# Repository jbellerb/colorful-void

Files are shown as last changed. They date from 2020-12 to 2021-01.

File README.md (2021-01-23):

# Colorful Void

This is a monorepo for "colorful void", a work-in-progress smart accent light built from a recycled monitor's backlight assembly. See each folder for specific instructions about each component.

## Usage

At it's core, this project is an internet connected light, controllable with a simple JSON-based REST API. The lights in the panel are connected to a Raspberry Pi Zero W running [void-client](void-client/), which exposes an internal control API. While this API is designed to be platform-agnostic, the client is intended to be used with [void-server](void-server/), a relay server that allows the Google Smart Home platform to communicate with the light.

## Security

The void-client API is unsecured and should **never** be exposed to the public internet. While security was a goal of both programs, attack surface mitigation is always helpful—especially since void-client is running as root. If possible, run void-client and void-server on different machines and make sure the Raspberry Pi cannot be accessed from the internet. A VPN solution like Wireguard should be used to enable communication between the two machines.

## Google Smart Home Setup

Usage with the Google Smart Home platform is functional, but some usability aspects are incomplete, such as the lack of a proper login form and requiring a full setup every time void-server is restarted. These steps assume void-client is built and running on a Pi, void-server is built and running on a publically accessable domain with HTTPS, and there is some way for the two to talk (such as a Wireguard tunnel)

### Action Setup

First you must create an Actions on Google project. This is covered in steps 1-6 of [this Google Smart Home documentation page](https://developers.google.com/assistant/smarthome/develop/create#create-project). After that, click on "Account linking" in the side bar and fill out the OAuth Client Information. Client ID should be "google" and Client Secret should be whatever you set when building void-server. The Authorization URL should be `https://whatever-url-you-are-hosting-void-server-at/auth` and the Token URL is `https://whatever-url-you-are-hosting-void-server-at/token`. Finally, click on "Actions" in the side bar and set the Fulfillment URL to `https://whatever-url-you-are-hosting-void-server-at/fulfillment`.

### Logging In

To actually control the light, you need to log in using the Google Home app. In the app, tap Settings, Works with Google, and then whatever you named your Action (which should be prefixed by [test]). This will open a browser window which will 404 because I didn't bother to write a proper login endpoint. To login, you will need to rewrite the URL to another one. Given `https://whaterver-url-you-are-hosting-void-server-at/auth?...&state={state string}&...` visit `https://oauth-redirect.googleusercontent.com/r/{your Actions project id}?code={your authorization token from building void-server}&state={state string from earlier}`. The Google Home app should open again. Follow the remaining instructions in the app and the device should be set up.

<br />

#### License

<sup>
Copyright (C) Jared Beller, 2020-2021.
</sup>
<br />
<sup>
Released under the <a href="https://www.gnu.org/licenses/gpl-3.0.txt">GNU General Public License, Version 3</a> or later. See <a href="LICENSE">LICENSE</a> for more information.
</sup>

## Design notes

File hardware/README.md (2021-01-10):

# hardware

This folder contains hardware schematics and an optional controller PCB for connecting the control Raspberry Pi Zero W to the panel's WS2812 LED strip.

## Usage

The Raspberry Pi outputs at 3.3V while the WS2812 LEDs require 5V control signals, so a level shifter is needed to connect the two. For convenience, a PCB was designed to sit over the upper half of the Raspberry Pi's GPIO pins and interface between it and the LEDs. The PCB also routes power for both the LEDs and Pi, so only a single power supply is needed. Out of an abundance of caution, a 5V 4A power supply ([Adafruit product 1466](https://www.adafruit.com/product/1466)) was used to power the prototype. While the PCB is recommended for reliability, everything can also be hand-wired. When hand-wiring, pins 4-13 (excluding 7) of the SN74AHCT125 level shifter can be left disconnected. The data signal was not reliable on a breadboard, so building with one is not recommended. All components were purchased from Adafruit and are linked below.

## Bill of Materials

| Ref | Description | Part No. | Adafruit PID |
| --- | --- | --- | --- |
| J1  | Raspberry Pi Zero W Pins 1-12 | Zero W | [3400][P1] |
| J2  | 2-Pin 0.1" Pitch Terminal Block | KF120-2P | [2138][P2] |
| J3  | 3-Pin 0.1" Pitch Terminal Block | KF120-3P | [2136][P3] |
| U1  | Quad 3V to 5V Level-Shifter | SN74AHCT125 | [1787][P4] |
| R1  | 470 Ohm Resistor (1/4 Watt) | CF1/4WXJ470 | [2781][P5] |

[P1]: https://www.adafruit.com/product/3400
[P2]: https://www.adafruit.com/product/2138
[P3]: https://www.adafruit.com/product/2136
[P4]: https://www.adafruit.com/product/1787
[P5]: https://www.adafruit.com/product/2781

<br />

#### License

<sup>
Copyright (C) Jared Beller, 2021.
</sup>
<br />
<sup>
Released under the <a href="https://www.gnu.org/licenses/gpl-3.0.txt">GNU General Public License, Version 3</a> or later. See <a href="LICENSE">LICENSE</a> for more information.
</sup>

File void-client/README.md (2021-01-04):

# void-client

This folder contains software to control the panel's LED strip over the network.

## Building

This project requires a recent version of the Rust arm-unknown-linux-gnueabihf toolchain as well as libclang. See the README of [rs_ws281x](https://github.com/rpi-ws281x/rpi-ws281x-rust) for more information about setting this up. This program assumes the LED strip in the panel has 75 lights. If this is not the case for your build, modify the const `LED_COUNT` in [src/light.rs](src/light.rs).

## Usage

This program needs root permissions to run. Logging output is configured with the `RUST_LOG` environment variable. An example systemd unit file is provided in [../infrastructure/void-client.service](../infrastructure/void-client.service).

<br />

#### License

<sup>
Copyright (C) Jared Beller, 2020.
</sup>
<br />
<sup>
Released under the <a href="https://www.gnu.org/licenses/gpl-3.0.txt">GNU General Public License, Version 3</a> or later. See <a href="LICENSE">LICENSE</a> for more information.
</sup>

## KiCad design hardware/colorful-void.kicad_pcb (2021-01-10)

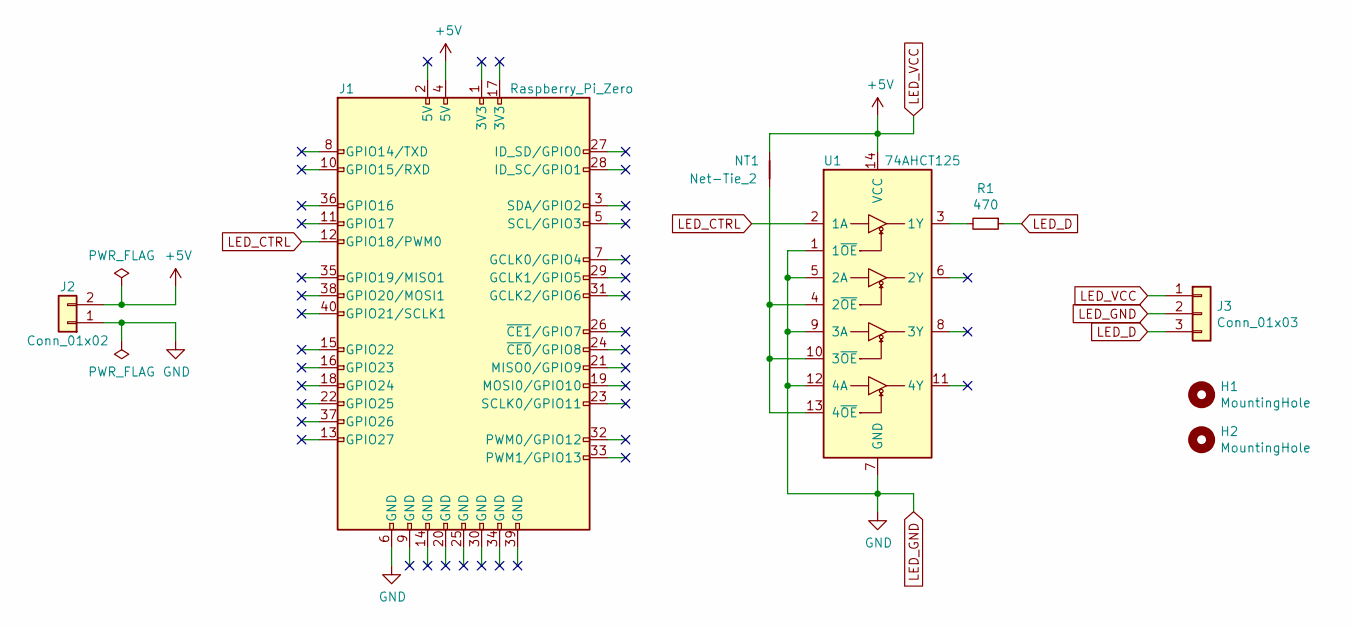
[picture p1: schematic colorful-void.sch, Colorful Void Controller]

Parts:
H1, H2: MountingHole; MountingHole_M2.5
J1: Raspberry_Pi_Zero; PinHeader_2x06_P2.54mm_Vertical
J2: Conn_01x02; TerminalBlock_Kaweei_1x02_P2.54mm_Horizontal
J3: Conn_01x03; TerminalBlock_Kaweei_1x03_P2.54mm_Horizontal
NT1: Net-Tie_2; NetTie-2_SMD_Pad0.5mm
R1: 470; R_Axial_DIN0309_L9.0mm_D3.2mm_P12.70mm_Horizontal
U1: 74AHCT125; DIP-14_W7.62mm

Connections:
LED_CTRL: J1.12 (GPIO18/PWM0), U1.2 (1A)
LED_D: J3.3, R1.1
LED_GND: J1.6 (GND), J2.1, J3.2, U1.1 (1~OE), U1.5 (2A), U1.7 (GND), U1.9 (3A), U1.12 (4A)
LED_VCC: J1.4 (5V), J2.2, J3.1, NT1.2, U1.14 (VCC)
unnamed: NT1.1, U1.4 (2~OE), U1.10 (3~OE), U1.13 (4~OE)
unnamed: R1.2, U1.3 (1Y)

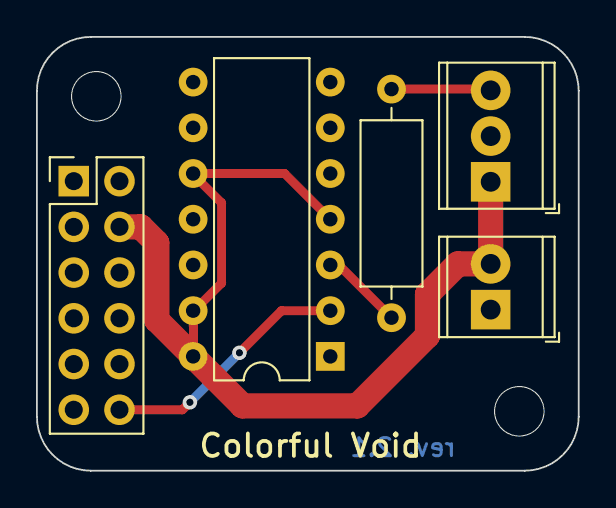
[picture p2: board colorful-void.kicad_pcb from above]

Board: 2 copper layers, 30.1 x 24.1 mm, 8 parts (0 on the bottom side), 6 nets.

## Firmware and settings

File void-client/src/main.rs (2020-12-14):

/*
 * Copyright (C) 2020  Jared Beller
 * This file is part of void-client
 *
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
 * You should have received a copy of the GNU General Public License
 * along with this program. If not, see <https://www.gnu.org/licenses/>.
 */

mod light;
mod proto;

use std::io::Cursor;

use light::Light;
use proto::{ActiveRequest, BrightnessRequest, ColorRequest, StatusRequest};

use anyhow::{anyhow, Result};
use log::debug;
use serde::Serialize;
use tiny_http::{Header, Method, Response, Server, StatusCode};

fn main() -> Result<()> {
    pretty_env_logger::init();

    let server = Server::http("0.0.0.0:8000").map_err(|e| anyhow!(e))?;

    let mut light = Light::new();

    for mut request in server.incoming_requests() {
        let response = match request.method() {
            Method::Get => match request.url() {
                "/" => {
                    debug!("Current status requested");

                    let response = StatusRequest {
                        active: light.get_active(),
                        brightness: light.get_brightness(),
                        color: light.get_color(),
                    };

                    Some(response_json(response)?)
                }
                "/active" => {
                    debug!("Current power requested");

                    let response = ActiveRequest {
                        value: light.get_active(),
                    };

                    Some(response_json(response)?)
                }
                "/brightness" => {
                    debug!("Current brightness requested");

                    let response = BrightnessRequest {
                        value: light.get_brightness(),
                    };

                    Some(response_json(response)?)
                }
                "/color" => {
                    debug!("Current color requested");

                    let response = ColorRequest {
                        value: light.get_color(),
                    };

                    Some(response_json(response)?)
                }
                _ => None,
            },
            Method::Put => {
                let mut body = String::new();
                request.as_reader().read_to_string(&mut body)?;

                match request.url() {
                    "/active" => {
                        let body: ActiveRequest = serde_json::from_str(&body)?;

                        debug!(
                            "Power change requested: {}",
                            if body.value { "on" } else { "off" }
                        );

                        light.set_active(body.value);

                        let response = ActiveRequest {
                            value: light.get_active(),
                        };

                        Some(response_json(response)?)
                    }
                    "/brightness" => {
                        let body: BrightnessRequest = serde_json::from_str(&body)?;

                        debug!("Brightness change requested: {}", body.value);

                        light.set_brightness(body.value);

                        let response = BrightnessRequest {
                            value: light.get_brightness(),
                        };

                        Some(response_json(response)?)
                    }
                    "/color" => {
                        let body: ColorRequest = serde_json::from_str(&body)?;

                        debug!("Color change requested: {}", body.value);

                        light.set_color(body.value);

                        let response = ColorRequest {
                            value: light.get_color(),
                        };

                        Some(response_json(response)?)
                    }
                    _ => None,
                }
            }
            _ => None,
        };

        let response =
            response.unwrap_or_else(|| Response::from_string("Not found").with_status_code(404));
        request.respond(response)?;
    }

    Ok(())
}

fn response_json<J>(json: J) -> Result<Response<Cursor<Vec<u8>>>>
where
    J: Serialize,
{
    let json = serde_json::to_vec(&json)?;
    let json_len = json.len();

    Ok(Response::new(
        StatusCode(200),
        vec![Header::from_bytes(
            &b"Content-Type"[..],
            &b"application/json; charset=UTF-8"[..],
        )
        .unwrap()],
        Cursor::new(json),
        Some(json_len),
        None,
    ))
}

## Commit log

2020-12-13 Initial hardware revision
    [colorful-void.sch]
2020-12-25 Fix permissions
    [colorful-void.sch]
2020-12-25 Connect client to RGB strip
    [colorful-void.sch]
2021-01-03 PCB rev. 1
    [colorful-void.kicad_pcb, colorful-void.sch]
2021-01-10 Current limiting resistor on LED data line
    [colorful-void.kicad_pcb, colorful-void.sch]
2021-01-10 Minor PCB routing optimization
    [colorful-void.kicad_pcb]

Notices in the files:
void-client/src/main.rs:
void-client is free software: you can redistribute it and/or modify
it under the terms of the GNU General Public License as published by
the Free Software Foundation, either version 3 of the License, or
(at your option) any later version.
